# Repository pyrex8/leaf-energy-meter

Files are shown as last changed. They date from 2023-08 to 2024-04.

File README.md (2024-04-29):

# leaf-energy-meter

The Nissan Leaf Energy Meter displays kWh remaining battery energy using data from the Nissan Leafs EV CAN bus.

Display installed in dash
<p align="center">
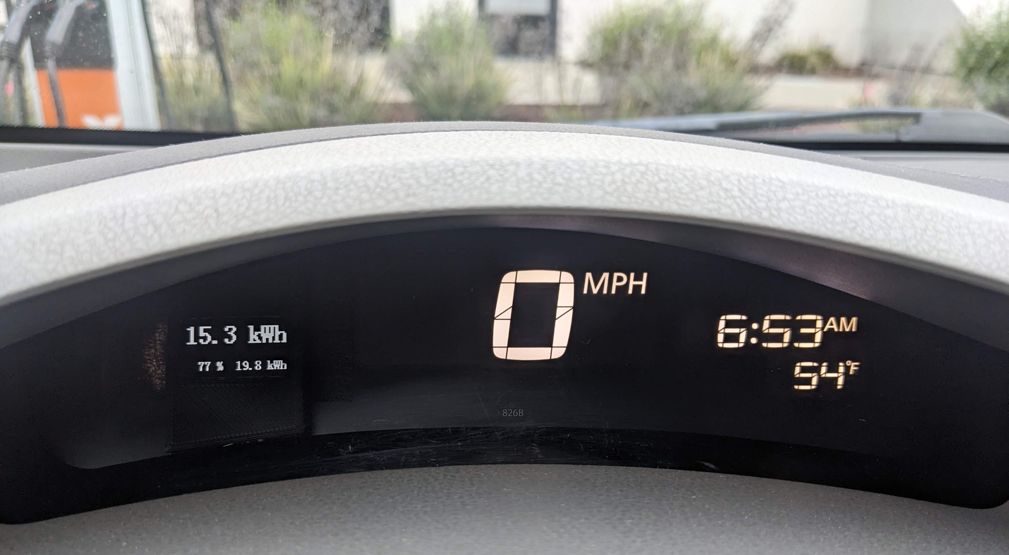
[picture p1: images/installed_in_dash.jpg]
finished
  

Display explaination
<p align="center">
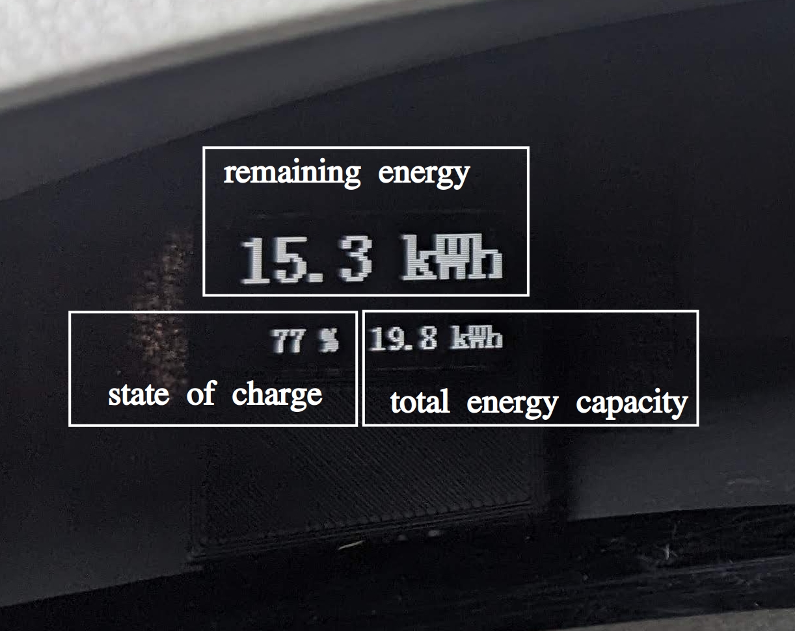
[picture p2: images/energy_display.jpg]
energy_display
  

Total energy is calculated from remaining energy and state of cahrge CAN bus data:

```total energy capacity = remaining energy / state of charge```

Note: total energy capacity does fluctuate a small amount while driving.

Display fully enclosed in 2011-2012 Nissan Leaf Upper Speedometer Combination Meter Display 24810-3NA1A
<p align="center">
  <img src="images/display_mounted.jpg" alt="display_mounted" width="400"/>

Wires fed through back 
<p align="center">
  <img src="images/display_connector.jpg" alt="connector" width="400"/>

Black painters tape is used to cover the "christmas" tree efficiency indicator
<p align="center">
  <img src="images/display_bezel_black_tape.jpg" alt="mounting" width="400"/>

Display and bezel mounted with Kapton tape
<p align="center">
  <img src="images/display_mounting.jpg" alt="findisplay_mountingished" width="400"/>

Soldering wires to OLED display 
<p align="center">
  <img src="images/display_soldering.jpg" alt="findisplay_mountingished" width="400"/>

Meter PCB in case
<p align="center">
  <img src="images/meter_pcb_in_case.jpg" alt="meter_pcb_in_case" width="400"/>

Code is using arduino
https://www.arduino.cc

<p align="center">
  <img src="images/arduino_editor.png" alt="arduino" width="800"/>

The schematics and pcb layout were made using diptrace. Files in ```pcb``` folder
https://diptrace.com

<p align="center">
  <img src="images/schematics.png" alt="schematics" width="800"/>

### Parts list

| approx. cost each | description | image |
| :---:   | :---: | :---: |
| $5 | Pro Mini Atmega328P 5V 16MHz for Arduino| <img src="images/arduino.png" alt="arduino" width="100"/> |
| $2 | Mini360 MP1584EN 5V Regulator, DC 5-30V to 5V 1.8A Output Buck Converter Board | <img src="images/dc-dc.png" alt="dc-dc" width="100"/> |
| $4 | MCP2515 CAN Bus Module TJA1050 Receiver SPI Module for Arduino | <img src="images/can.png" alt="can" width="50"/> |
| $7 | SSD1306 0.96" 128X64 OLED Display I2C Font Color White | <img src="images/oled.png" alt="oled" width="100"/> |
| $0.5 | JST XH 2.54 4 Pin Connector Plug Male with 200mm Wire & Female Connector | <img src="images/jst.png" alt="jst" width="100"/> |
| $8 | OBDII Male Connector with enclosure | <img src="images/enclosure.png" alt="enclosure" width="100"/> |

The pcb is shared on OSH Park
https://oshpark.com/projects/Czkf2fi5/view_design

<p align="center">
  <img src="images/pcb_top.png" alt="pcb" width="400"/>

### Wiring to OBDII connector
- pin 4, chassis ground
- pin 8, +12V DC when vehicle is powered is on
- pin 12, EV-CAN low
- pin 13, EV-CAN high

<p align="center">
  <img src="images/obd2_male_backshell_wiring.png" alt="enclosure" width="200"/>

bezel is design using OpenSCAD. Files in ```bezel``` folder
https://openscad.org/

<p align="center">
  <img src="images/bezel_openscad.png" alt="bezel" width="800"/>

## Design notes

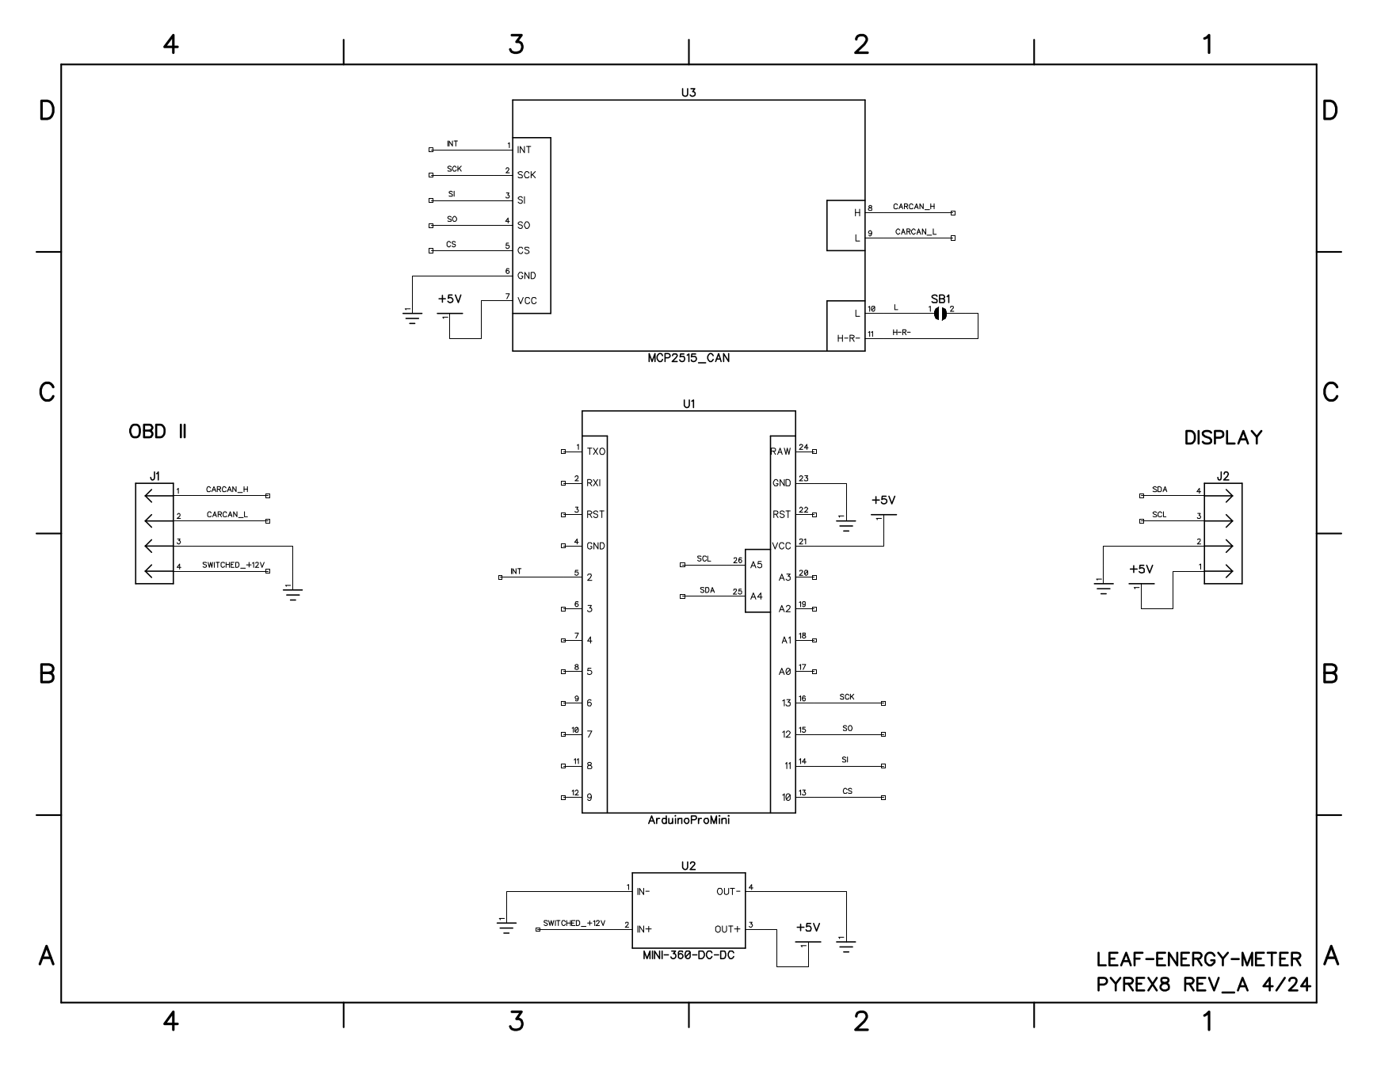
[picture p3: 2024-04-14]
images/schematics.png

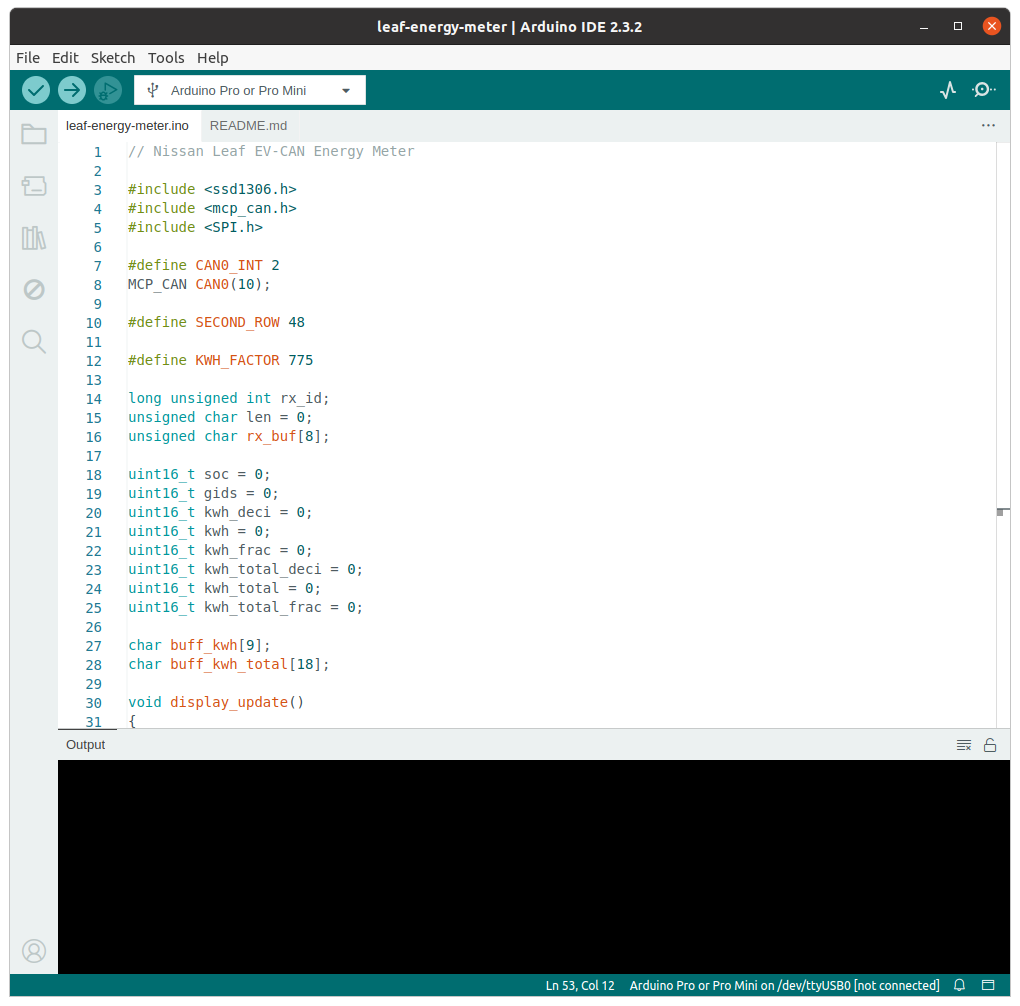
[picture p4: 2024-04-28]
images/arduino_editor.png

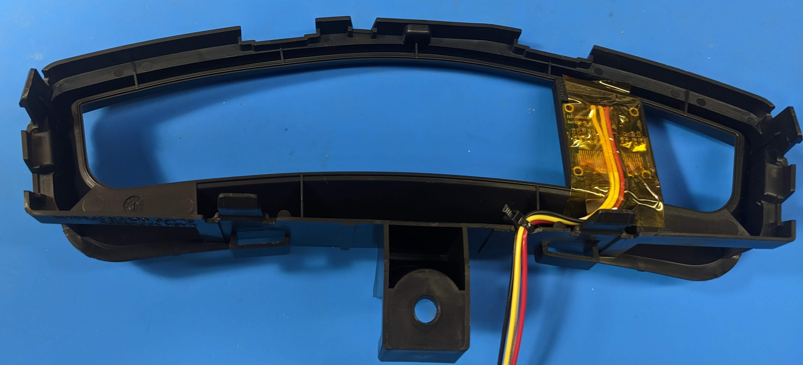
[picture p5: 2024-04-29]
images/display_mounting.jpg

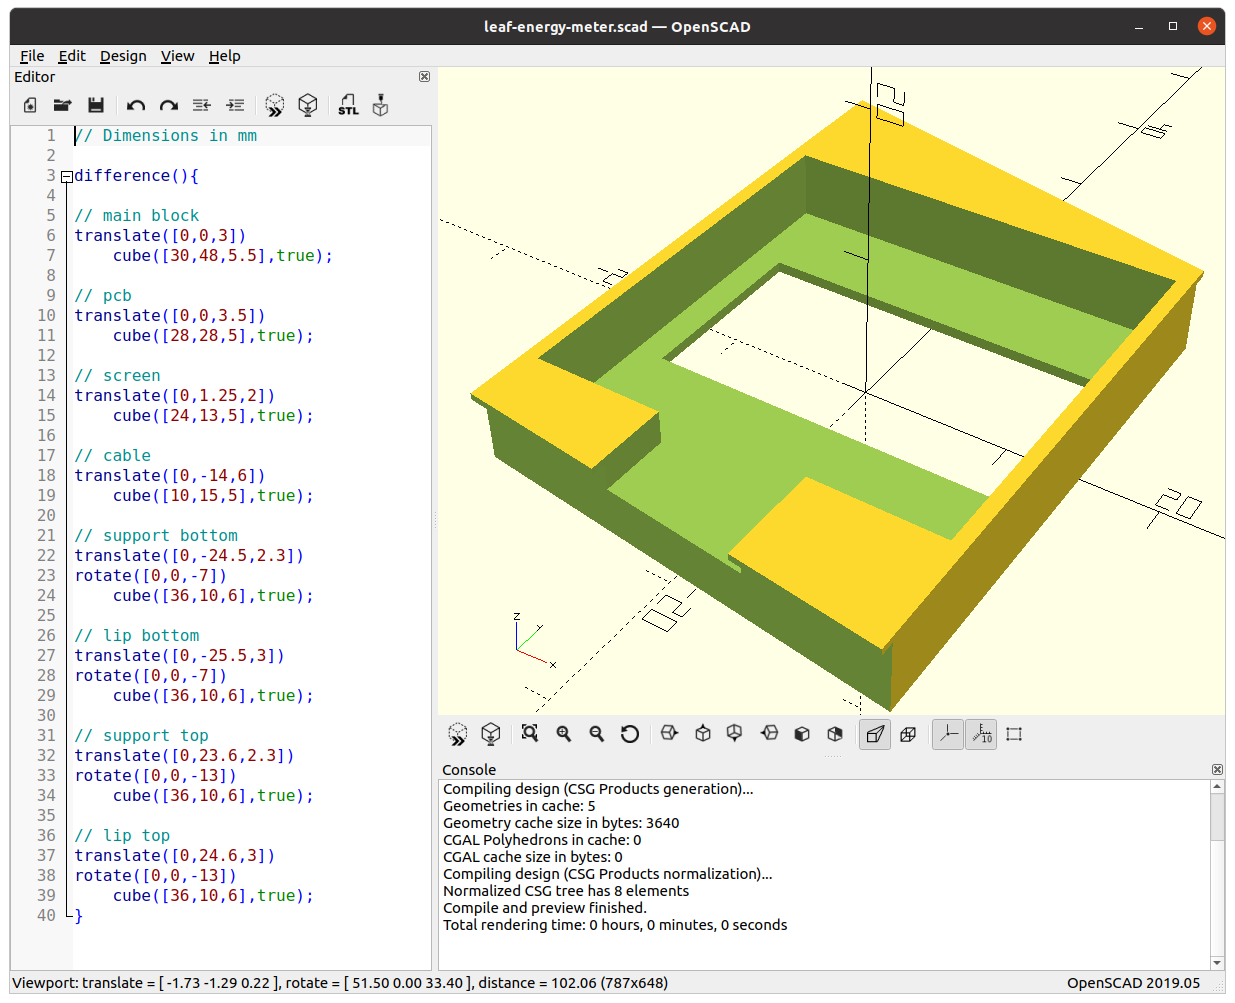
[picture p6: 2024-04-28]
images/bezel_openscad.png

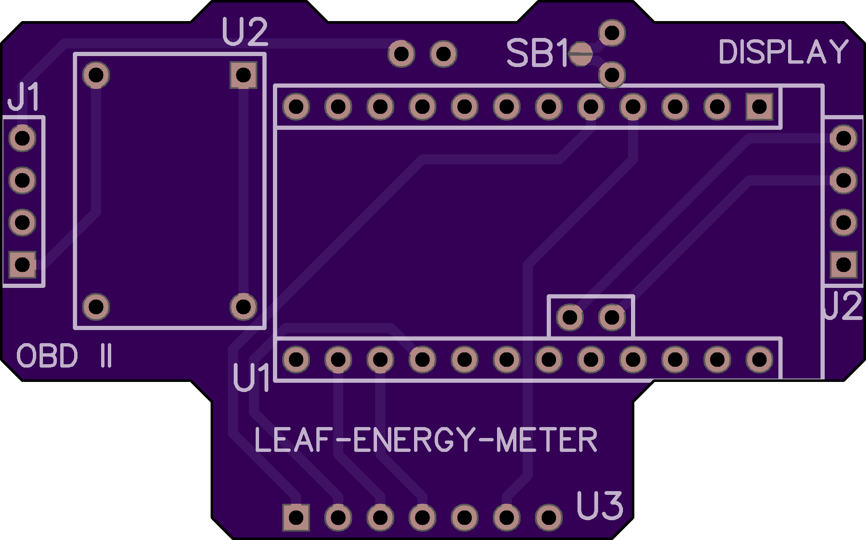
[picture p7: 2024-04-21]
images/pcb_top.png

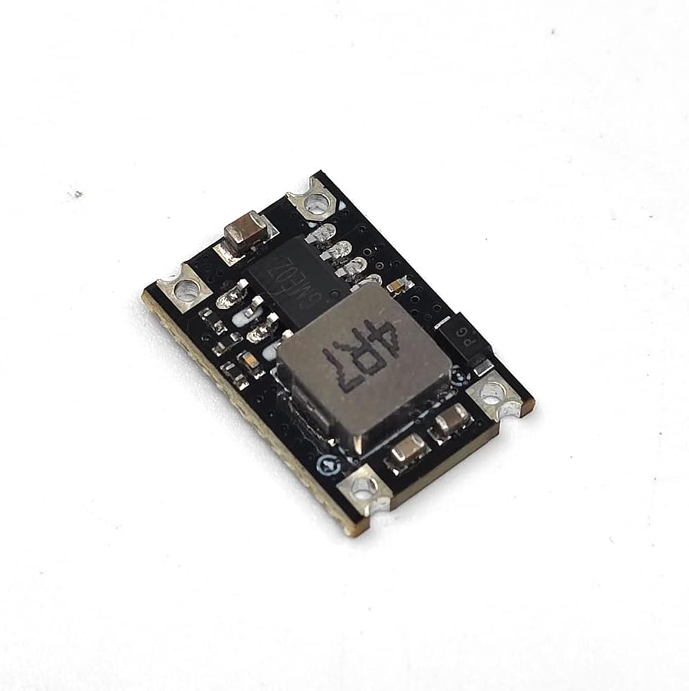
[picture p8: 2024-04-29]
images/dc-dc.png

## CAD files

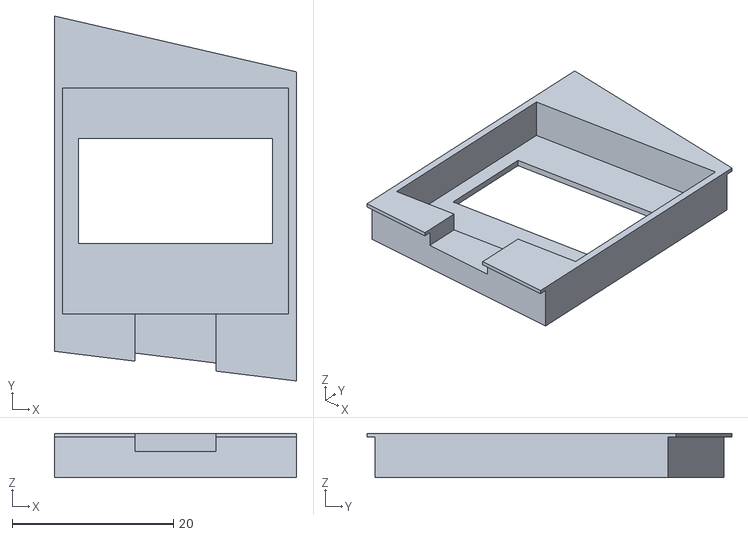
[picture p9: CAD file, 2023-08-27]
bezel/leaf-energy-meter.stl
30.0 x 45.2 x 5.50

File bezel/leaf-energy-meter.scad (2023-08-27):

// Dimensions in mm

difference(){  
      
// main block    
translate([0,0,3])
    cube([30,48,5.5],true);

// pcb
translate([0,0,3.5])
    cube([28,28,5],true);

// screen
translate([0,1.25,2])
    cube([24,13,5],true);
    
// cable
translate([0,-14,6])
    cube([10,15,5],true);
    
// support bottom
translate([0,-24.5,2.3])
rotate([0,0,-7])
    cube([36,10,6],true);

// lip bottom
translate([0,-25.5,3])
rotate([0,0,-7])
    cube([36,10,6],true);

// support top
translate([0,23.6,2.3])
rotate([0,0,-13])
    cube([36,10,6],true);
    
// lip top 
translate([0,24.6,3])
rotate([0,0,-13])
    cube([36,10,6],true);    
}

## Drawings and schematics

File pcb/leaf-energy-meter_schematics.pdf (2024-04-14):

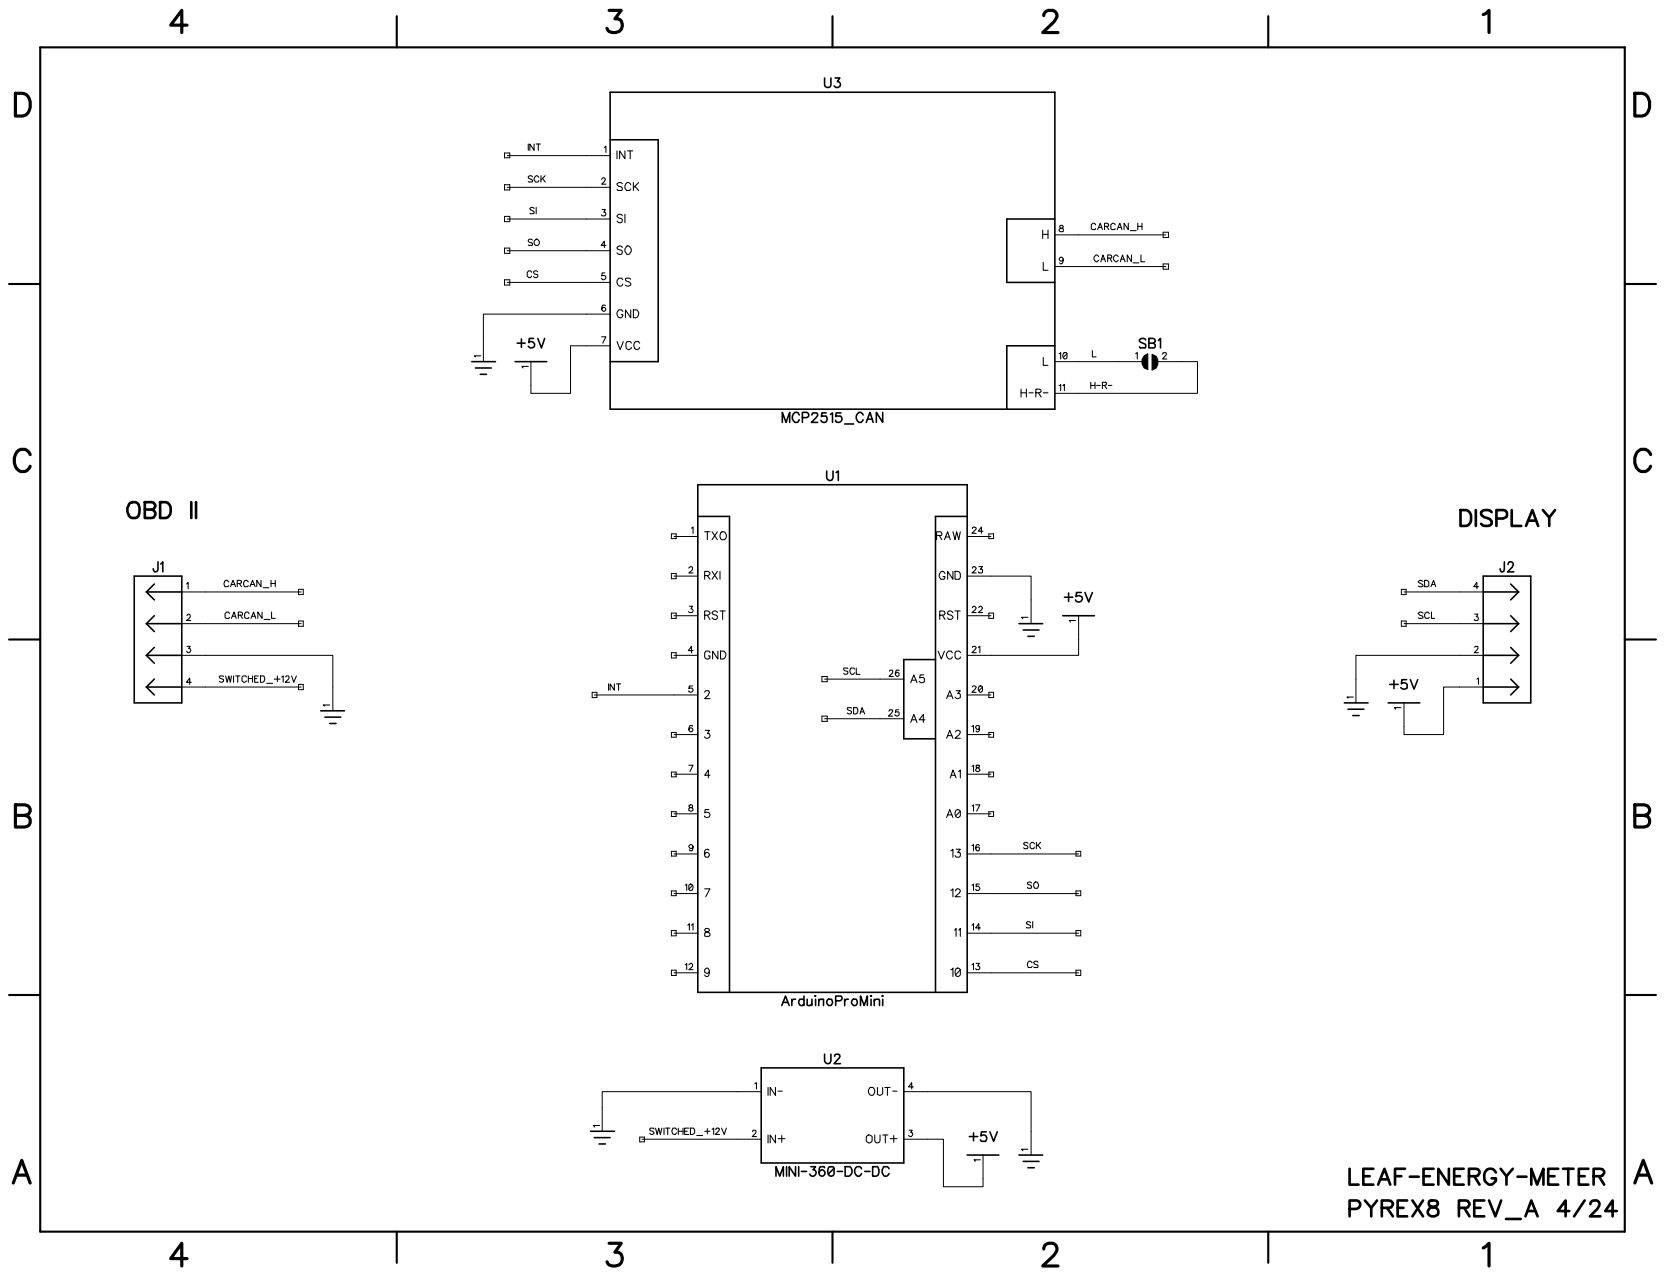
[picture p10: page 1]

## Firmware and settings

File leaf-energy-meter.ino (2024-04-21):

// Nissan Leaf EV-CAN Energy Meter

#include <ssd1306.h>
#include <mcp_can.h>
#include <SPI.h>

#define CAN0_INT 2
MCP_CAN CAN0(10);

#define SECOND_ROW 48

#define KWH_FACTOR 775

long unsigned int rx_id;
unsigned char len = 0;
unsigned char rx_buf[8];

uint16_t soc = 0;
uint16_t gids = 0;
uint16_t kwh_deci = 0;
uint16_t kwh = 0;
uint16_t kwh_frac = 0;
uint16_t kwh_total_deci = 0;
uint16_t kwh_total = 0;
uint16_t kwh_total_frac = 0;

char buff_kwh[9];
char buff_kwh_total[18];

void display_update()
{
  sprintf(buff_kwh, "%2d.%01d kWh", kwh, kwh_frac);
  sprintf(buff_kwh_total, "  %2d %%  %2d.%01d kWh", soc, kwh_total, kwh_total_frac);
  ssd1306_printFixed2x(0, 0, buff_kwh, STYLE_BOLD);
  ssd1306_printFixed(0, SECOND_ROW, buff_kwh_total, STYLE_BOLD);
}

void setup()
{
  ssd1306_128x64_i2c_init();
  ssd1306_setFixedFont(ssd1306xled_font8x16);
  ssd1306_clearScreen();
  CAN0.begin(MCP_STDEXT, CAN_500KBPS, MCP_8MHZ);
  CAN0.init_Mask(0, 0, 0x07ff0000);
  CAN0.init_Filt(0, 0, 0x055b0000);
  CAN0.init_Mask(1, 0, 0x07ff0000);
  CAN0.init_Filt(2, 0, 0x05bc0000);
  CAN0.setMode(MCP_NORMAL);
  pinMode(CAN0_INT, INPUT);
  display_update();
}

void loop()
{
  if (!digitalRead(CAN0_INT))
  {
    CAN0.readMsgBuf(&rx_id, &len, rx_buf);

    if (rx_id == 0x55b) // 100ms
    {
      soc = ((rx_buf[0] << 2) | (rx_buf[1] >> 6)) / 10;
    }

    if (rx_id == 0x5bc) // 500ms
    {
      gids = (rx_buf[0] << 2) | (rx_buf[1] >> 6);
      kwh_deci = (int16_t)(((int32_t)gids * KWH_FACTOR) / 1000);

      kwh = kwh_deci / 10;
      kwh_frac = kwh_deci % 10;

      if (soc > 0)
      {
        kwh_total_deci = (kwh_deci * 100) / soc;

        kwh_total = kwh_total_deci / 10;
        kwh_total_frac = kwh_total_deci % 10;
      }

      display_update();
    }
  }
}

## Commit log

2023-08-05 arduino meter
2023-08-08 update to Ahr meter to flash 25% on when power is off
2023-08-11 fix ah_count_trip -sign issue
    [leaf-energy-meter.ino]
2023-08-11 fixed sign on Ah display
    [leaf-energy-meter.ino]
2023-08-12 trying out kWh vs Ah from battery values
2023-08-12 working on mph and miles driven from wheel sensor
2023-08-15 back to EV-CAN bus
2023-08-15 miles/kwh might be fixed , needs testing
    [leaf-energy-meter.ino]
2023-08-17 switched to CAR-CAN
2023-08-18 back to EV-CAN, fix to put fast data in separate MCP2515 buffers
    [leaf-energy-meter.ino]
2023-08-20 start of openscad bezel drawing
    [leaf-energy-meter.scad]
2023-08-21 working on angled edge
    [leaf-energy-meter.scad, leaf-energy-meter.stl]
2023-08-22 appoximation of curve in instrument cluster
    [leaf-energy-meter.scad, leaf-energy-meter.stl]
2023-08-26 pretty good fit in speedometer instrument cluster
    [leaf-energy-meter.scad, leaf-energy-meter.stl]
2023-08-27 final version in car
    [leaf-energy-meter.scad, leaf-energy-meter.stl]
2024-04-12 add fritz schemtatics
    [leaf-energy-meter.fzz]
2024-04-14 adding pcb
    [leaf-energy-meter.fzz, leaf-energy-meter.scad, leaf-energy-meter.stl]
2024-04-14 update pcb and images
    [leaf-energy-meter.fzz]
2024-04-28 add arduino detail
2024-04-29 total energy capacity equation
